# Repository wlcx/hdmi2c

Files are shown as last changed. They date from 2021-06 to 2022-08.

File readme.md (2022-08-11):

# HDMI2C Monitor Controller

HDMI2C allows network control (via WiFi) of monitors connected to it via HDMI (via
[DDC]). This allows you to build your own tooling and control systems for your monitors,
rather than relying on awkward inconvient buttons and OSDs. Think of it as an API for
your monitors.

This repository contains the hardware design, made with [KiCAD]. You can see the
generated BOM and schematic [here][pages].

## What could you build with this

- A physical brightness knob
- Switch inputs of both monitors simultaneously when you wake up your desktop PC or
  connect your laptop to your dock
- IDK probably some other weird shit

## Features

- ESP32 WiFi MCU
- USB-C power and MCU serial connection
  - With blinkenlights
- Two HDMI ports with:
  - Level shifters to bring 5v DDC signals to 3.3v for the MCU.
  - 5v HDMI presence detection, switchable from the MCU. This allows us to fake being
    unplugged and replugged from HDMI, if we need to.
- Two forward facing buttons

## Firmware

It's floating around somewhere, I'll tidy it up and upload it at some point.

## A word on monitor compatibility

Not all monitors implement DDC that well. Particularly of annoyance, some models I
tested would not listen to DDC commands on inputs that were not active, which, given
this project relies on you having a spare HDMI input which never carries any video, is
kind of a deal breaker.

### Known good monitors

- Dell U2515h - I personally have two of these and they work flawlessly.

## Improvements for next rev

- Just use M3 mounting holes, M2.5 was a terrible idea
- Spare ESP32 IO broken out to headers for ease of hacking
- More ambitious, HDMI passthrough to allow use of the project without taking up a whole
  spare HDMI port.

## Is it that useful tho?

You can achieve the same thing without having to build your own hardware with a
Raspberry Pi 4. Support for dual monitor I2C (DDC) was added shortly before I started
this project - guess I didn't check enough :-). This is a much more accessible means to
achieve the same goal. However, if you want a more minimal solution that doesn't require
an entire embedded linux system, this project may be for you.

[DDC]: https://en.wikipedia.org/wiki/Display_Data_Channel
[KiCAD]: https://kicad.org
[pages]: https://wlcx.github.io/hdmi2c

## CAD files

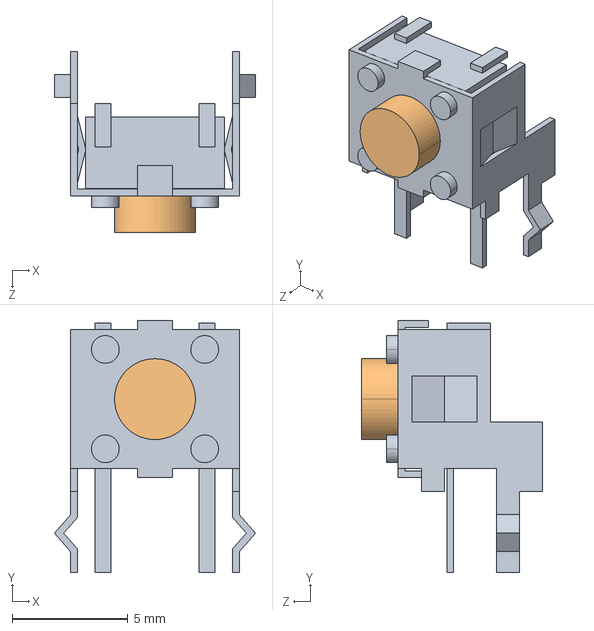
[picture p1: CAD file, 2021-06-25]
3d/B3F-3122.STEP
8.70 x 10.9 x 7.85 mm
B3F_3122_BASE
B3F_3122_BUTTON

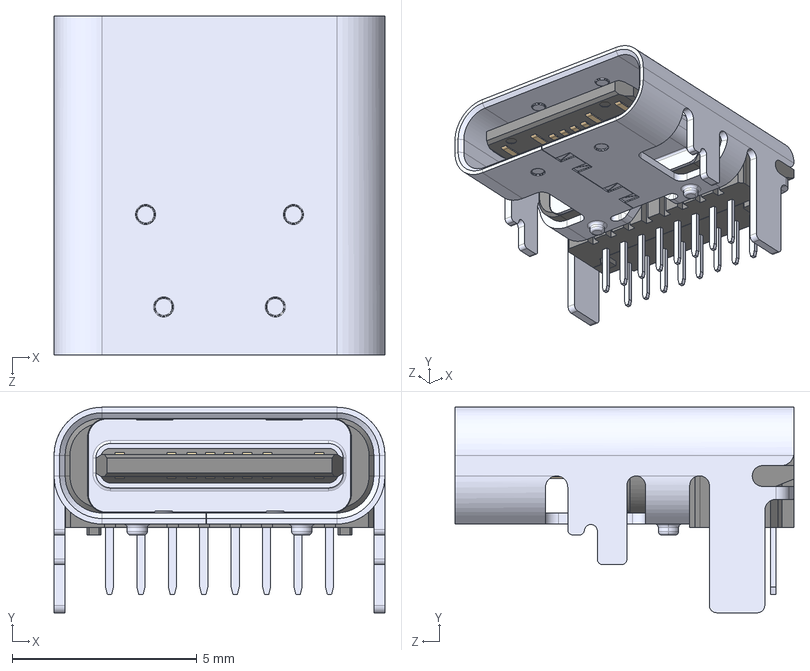
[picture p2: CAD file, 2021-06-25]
3d/USB_C_Receptacle_GCT_USB4085.STEP
8.95 x 5.56 x 9.17 mm

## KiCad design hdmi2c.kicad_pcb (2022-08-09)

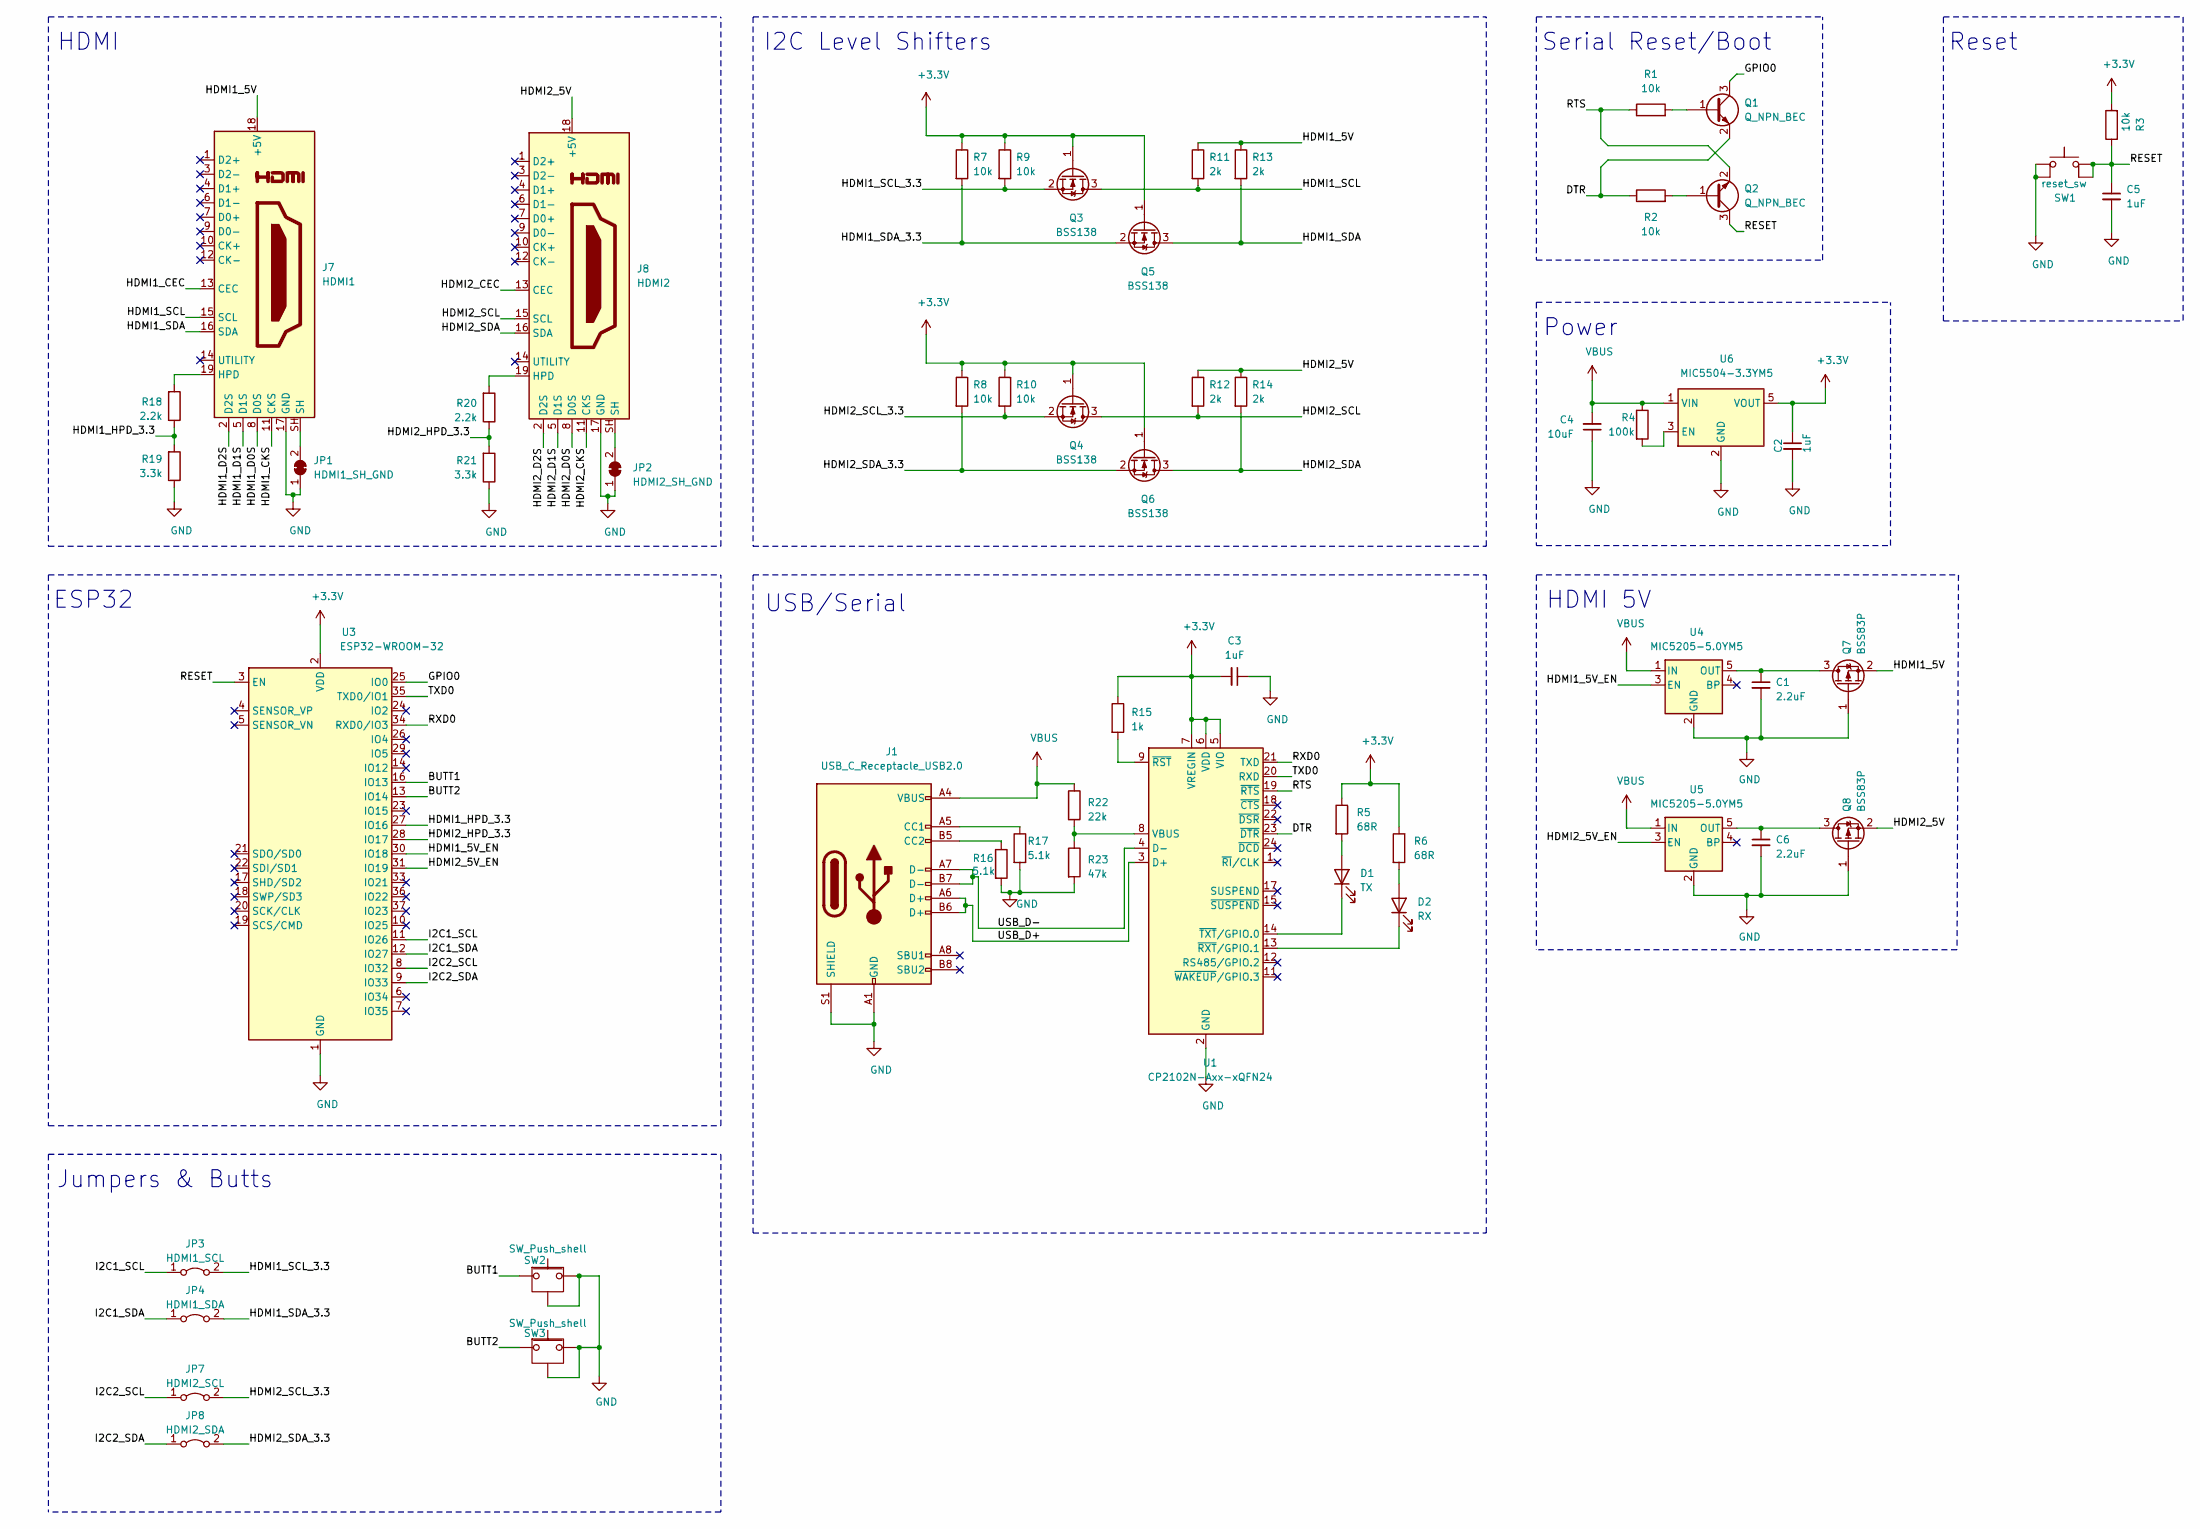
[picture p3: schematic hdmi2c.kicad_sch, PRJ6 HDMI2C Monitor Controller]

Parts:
C1, C6: 2.2uF; C_0603_1608Metric
C2, C3, C5: 1uF; C_0603_1608Metric
C4: 10uF; C_0603_1608Metric
D1: TX; LED_0603_1608Metric
D2: RX; LED_0603_1608Metric
J1: USB_C_Receptacle_USB2.0; USB_C_Receptacle_GCT_USB4085
J7: HDMI1; WURTH_685119134923_HDMI
J8: HDMI2; WURTH_685119134923_HDMI
JP1: HDMI1_SH_GND; SolderJumper-2_P1.3mm_Open_RoundedPad1.0x1.5mm
JP2: HDMI2_SH_GND; SolderJumper-2_P1.3mm_Open_RoundedPad1.0x1.5mm
JP3: HDMI1_SCL; SolderJumper-2_P1.3mm_Bridged_RoundedPad1.0x1.5mm
JP4: HDMI1_SDA; SolderJumper-2_P1.3mm_Bridged_RoundedPad1.0x1.5mm
JP7: HDMI2_SCL; SolderJumper-2_P1.3mm_Bridged_RoundedPad1.0x1.5mm
JP8: HDMI2_SDA; SolderJumper-2_P1.3mm_Bridged_RoundedPad1.0x1.5mm
Q1, Q2: Q_NPN_BEC; SOT-23
Q3, Q4, Q5, Q6: BSS138; SOT-23
Q7, Q8: BSS83P; SOT-23
R1, R2, R3, R7, R8, R9, R10: 10k; R_0603_1608Metric
R4: 100k; R_0603_1608Metric
R5, R6: 68R; R_0603_1608Metric
R11, R12, R13, R14: 2k; R_0603_1608Metric
R15: 1k; R_0603_1608Metric
R16, R17: 5.1k; R_0603_1608Metric
R18, R20: 2.2k; R_0603_1608Metric
R19, R21: 3.3k; R_0603_1608Metric
R22: 22k; R_0603_1608Metric
R23: 47k; R_0603_1608Metric
SW1: reset_sw; SW_SPST_Omron_B3FS-101xP
SW2, SW3: SW_Push_shell; SW_TH_Tactile_Omron_B3F-312x
U1: CP2102N-Axx-xQFN24; QFN-24-1EP_4x4mm_P0.5mm_EP2.6x2.6mm
U3: ESP32-WROOM-32
U4, U5: MIC5205-5.0YM5; SOT-23-5
U6: MIC5504-3.3YM5; SOT-23-5

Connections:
+3V3: C2.1, C3.2, Q3.1 (G), Q4.1 (G), Q5.1 (G), Q6.1 (G), R3.2, R5.1, R6.1, R7.1, R8.1, R9.1, R10.1, R15.1, U1.5 (VIO), U1.6 (VDD), U1.7 (VREGIN), U3.2 (VDD), U6.5 (VOUT)
/BUTT1: SW2.1, U3.16 (IO13)
/BUTT2: SW3.1, U3.13 (IO14)
/DTR: Q1.2 (E), R2.1, U1.23 (~DTR)
/GPIO0: Q1.3 (C), U3.25 (IO0)
/HDMI1_5V: J7.18 (+5V), Q7.2 (S), R11.1, R13.1
/HDMI1_5V_EN: U3.30 (IO18), U4.3 (EN)
/HDMI1_CEC: J7.13 (CEC)
/HDMI1_CKS: J7.11 (CKS)
/HDMI1_D0S: J7.8 (D0S)
/HDMI1_D1S: J7.5 (D1S)
/HDMI1_D2S: J7.2 (D2S)
/HDMI1_HPD_3.3: R18.1, R19.2, U3.27 (IO16)
/HDMI1_SCL: J7.15 (SCL), Q3.3 (D), R11.2
/HDMI1_SCL_3.3: JP3.2 (B), Q3.2 (S), R9.2
/HDMI1_SDA: J7.16 (SDA), Q5.3 (D), R13.2
/HDMI1_SDA_3.3: JP4.2 (B), Q5.2 (S), R7.2
/HDMI2_5V: J8.18 (+5V), Q8.2 (S), R12.1, R14.1
/HDMI2_5V_EN: U3.31 (IO19), U5.3 (EN)
/HDMI2_CEC: J8.13 (CEC)
/HDMI2_CKS: J8.11 (CKS)
/HDMI2_D0S: J8.8 (D0S)
/HDMI2_D1S: J8.5 (D1S)
/HDMI2_D2S: J8.2 (D2S)
/HDMI2_HPD_3.3: R20.1, R21.2, U3.28 (IO17)
/HDMI2_SCL: J8.15 (SCL), Q4.3 (D), R12.2
/HDMI2_SCL_3.3: JP7.2 (B), Q4.2 (S), R10.2
/HDMI2_SDA: J8.16 (SDA), Q6.3 (D), R14.2
/HDMI2_SDA_3.3: JP8.2 (B), Q6.2 (S), R8.2
/I2C1_SCL: JP3.1 (A), U3.11 (IO26)
/I2C1_SDA: JP4.1 (A), U3.12 (IO27)
/I2C2_SCL: JP7.1 (A), U3.8 (IO32)
/I2C2_SDA: JP8.1 (A), U3.9 (IO33)
/RESET: C5.1, Q2.3 (C), R3.1, SW1.3, SW1.4, U3.3 (EN)
/RTS: Q2.2 (E), R1.1, U1.19 (~RTS)
/RXD0: U1.21 (TXD), U3.34 (RXD0/IO3)
/TXD0: U1.20 (RXD), U3.35 (TXD0/IO1)
/USB_D+: J1.A6 (D+), J1.B6 (D+), U1.3 (D+)
/USB_D-: J1.A7 (D-), J1.B7 (D-), U1.4 (D-)
GND: C1.2, C2.2, C3.1, C4.1, C5.2, C6.2, J1.A1 (GND), J1.A12 (GND), J1.B1 (GND), J1.B12 (GND), J1.S1 (SHIELD), J7.17 (GND), J8.17 (GND), JP1.1 (A), JP2.1 (A), Q7.1 (G), Q8.1 (G), R16.2, R17.2, R19.1, R21.1, R23.2, SW1.1, SW1.2, SW2.2, SW2.SH (Shell), SW3.2, SW3.SH (Shell), U1.2 (GND), U1.25 (GND), U3.1 (GND), U3.15 (GND), U3.38 (GND), U3.39 (GND), U4.2 (GND), U5.2 (GND), U6.2 (GND)
unnamed: C1.1, Q7.3 (D), U4.5 (OUT)
unnamed: C6.1, Q8.3 (D), U5.5 (OUT)
unnamed: D1.1 (K), U1.14 (~TXT~/GPIO.0)
unnamed: D1.2 (A), R5.2
unnamed: D2.1 (K), U1.13 (~RXT~/GPIO.1)
unnamed: D2.2 (A), R6.2
unnamed: J1.A5 (CC1), R17.1
unnamed: J1.B5 (CC2), R16.1
unnamed: J7.19 (HPD), R18.2
unnamed: J7.SH, JP1.2 (B)
unnamed: J8.19 (HPD), R20.2
unnamed: J8.SH, JP2.2 (B)
unnamed: Q1.1 (B), R1.2
unnamed: Q2.1 (B), R2.2
unnamed: R4.2, U6.3 (EN)
unnamed: R15.2, U1.9 (~RST)
unnamed: R22.2, R23.1, U1.8 (VBUS)
VBUS: C4.2, J1.A4 (VBUS), J1.A9 (VBUS), J1.B4 (VBUS), J1.B9 (VBUS), R4.1, R22.1, U4.1 (IN), U5.1 (IN), U6.1 (VIN)

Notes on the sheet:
I2C Level Shifters
Reset
HDMI 5V
Power
Serial Reset/Boot
HDMI
USB/Serial
Jumpers & Butts
ESP32

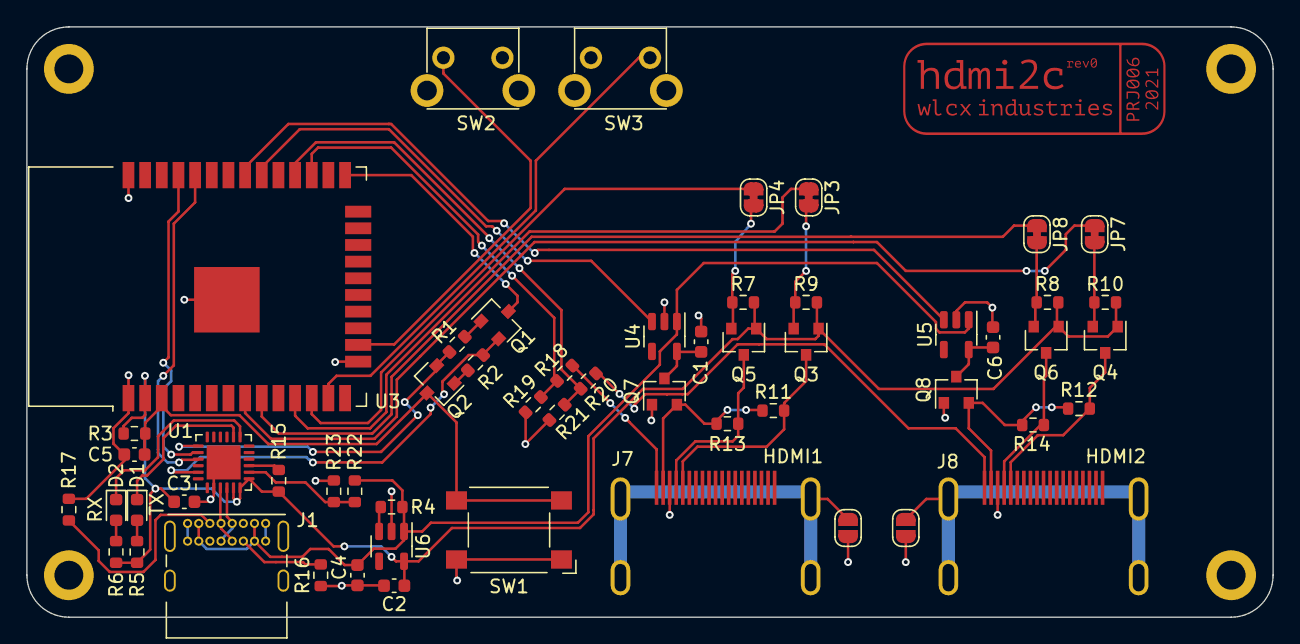
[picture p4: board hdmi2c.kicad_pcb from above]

Board: 2 copper layers, 95.0 x 45.0 mm, 61 parts (0 on the bottom side), 48 nets.

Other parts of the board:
M1, M2, M3, M4: MountingHole_2.2mm_M2_DIN965_Pad_with_paste
svg2mod: G***; logo

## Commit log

2021-06-25 Rev 0
    [B3F-3122.STEP, USB_C_Receptacle_GCT_USB4085.STEP, hdmi2c.kicad_pcb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]
2021-06-25 Add interactive BOM gh action
2021-06-25 Update PCB sheet properties
    [hdmi2c.kicad_pcb]
2022-08-09 Save project files with newest kicad version
    [hdmi2c.kicad_pcb, hdmi2c.kicad_sch]
2022-08-09 Update schematic/pcb metadata to match
    [hdmi2c.kicad_pcb, hdmi2c.kicad_sch]
